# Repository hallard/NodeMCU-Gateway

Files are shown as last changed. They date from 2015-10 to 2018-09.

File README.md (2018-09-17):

NodeMCU ESP8266 Gateway Goes to WeMos ESP8266
=============================================

This gateway has been updated by a new version for the following reasons:

- Now I'm using [WeMos D1 Mini][9] board instead of NodeMCU's one because they're just smaller and cheaper (you can find them for less than $3). 
- Features remains the same, they got lot of available shields
- USB Serial onboard is CH340 instead of CP210x, and I can upload up to 900Kbps without any issue on windows 10
- I suspect WeMos regulator far better quality than the one used on NodeMCU that are just fake of original AMS117 3V3.
- Just one size version, no error on order are possible!
- Only one drawback, Voltage input on WeMos is limited to 6V and NodeMCU says up to 20V but trust me, I burnt some at only 14V so If I need to power boards with more than 6V I'm using cheap and small DC/DC converters like this [one][20]one. Plenty on ebay. If you need a more serious and robust one, take this amazing [OKI-78SR-5][21] from Murata (up to 36V).

So for all these reasons I switched to WeMos and created same shields than the ones described here, but, due to size constraint I removed some features, you need to be aware that the following ones has been removed on WeMos shields:

- SPI 2.2" or 1.8" TFT LCD connector
- SPI 128x64 OLED connector (I2C one still present)
- Grove I2C connector (but I2C is exposed via OLED connector)
- Lipo Battery connector
- Data connection for any cheap ebay ASK RX receiver
- **New, a push button** has been added to do some UI/Action if needed.

WeMos Gateway shields are located here: 
- Shield for [RFM69W, RFM69HW, RFM12B or RFM69CW][10] with Atmel ATSHA204 for crypto
- Shield for Lora/LoraWan [RFM92, RFM95, RFM96 or RFM98][11] with footprint for Microchip 24AA02E64 64 bits serial number
- **New Shield** for Lora/LoraWAN [Microchip RN2483][12] with footprint for excellent Microchip RN2483 Lora/Lorawan Module

Sorry there is no shield designed for NRF24L01.

If you need NRF24L01 version or if you just want to continue with the NodeMCU gateway you can, this repo is still alive and boards are working fine.

NodeMCU ESP8266 Gateway
=======================

The gateway can host several funny things like

- Socket to plug a NodeMCU V1.0 (take care 2 version with different width)
- Pins to connect I2C or SPI OLED 128x64
- Pins to connect 2.2" or 1.8" TFT LCD
- RFM69 or RFM12B on board module
- RFM69, RFM12B or NRF24L01 on board module (on NRF version)
- RFM92, RFM95, RFM96, RFM98, RFMH69, RFMHW69 or RFMHCW69 on board module (on LORA version)
- Lipo Battery connector for testing and move the Gateway (no charger on board)
- 3V3 On board regulator is provided by NodeMCU Board
- Data connection for any cheap ebay ASK RX receiver
- One Grove I2C connector to connect other I2C devices
- 2 onboard nice WS2812 RGB LED
- Footprint for Atmel ATSHA204 (I2C version due to lack of I/O)
- Footprint for Microchip 64 bits Unique ID 24AA02E64  (on LORA version)
- Created a version with NRF24L01 connector instead of a grove I2C (end of this page)
- SMA or UFL Antenna connector 

This page has been updated to reflect the GPIO changes and the PCB also, it's now V1.3.

NRF24L01 version are now tested thanks to [mannkind][6]. As suggested NRF version 1.2 has how been corrected to have NRF24L01 wiring same has mysensors configuration and added place for capacitor near NRF24L01.

LORA version have been tested by [lafleur][7] thanks to him.

Take care that on the market you can find lot of NODEMCU boards with different version, and they do not all fit on this. Just because sometime the width of the board if too high. Take care when you order a NodeMCU, see this [post][8]for explanations

New Version 1.3 boards
======================
New boards version V1.3 these boards have some improvments depending on version
- SMA/UFL Antenna connector has been size reduced
- Antenna trace and RF Module surrounded with via for better RF isolation
- Increased "Isolate" ground planes to avoid shorts between connectors and ground (may happen sometimes after soldering)
- I2C OLED connector is now "lock" version, you can just plug to test it will fit without connector
- No more LED solder pad to choose VIN/3V3, added 1N4148 diode from 5V for the 1st LED to decrease VCC to 4.4V, always works
- LORA version, added Microchip 64 bits Unique ID footprint 24AA02E64 
- LORA version, done a diode logic OR for DIO0/DIO1/DIO2 for current LIMC implementation

Version 1.2 boards
==================
New boards version V1.2 these boards add a MOSFET transistor to protect againns reversed power supply. Trust me this will avoid you to burn some nodeMCU board (but nobody plug reversed powed, never ?)

New board, supporing LORA modules

Version 1.1 boards
==================
Boards V1.1 are tested ok (RFM69), no problem at all, just SILK error on TFT connector, TFT pin 4 is RST or VIN (depending on solder pad) not GPIO0, also R3 10K is not needed since GPIO2 is already pulled up by 12K on nodeMCU boards.

SILK problem solved in V1.1a+, I also put VIN/RST solder pad bigger for easier soldering.

This is a bunch of V1.1 white PCB boards, nice ?

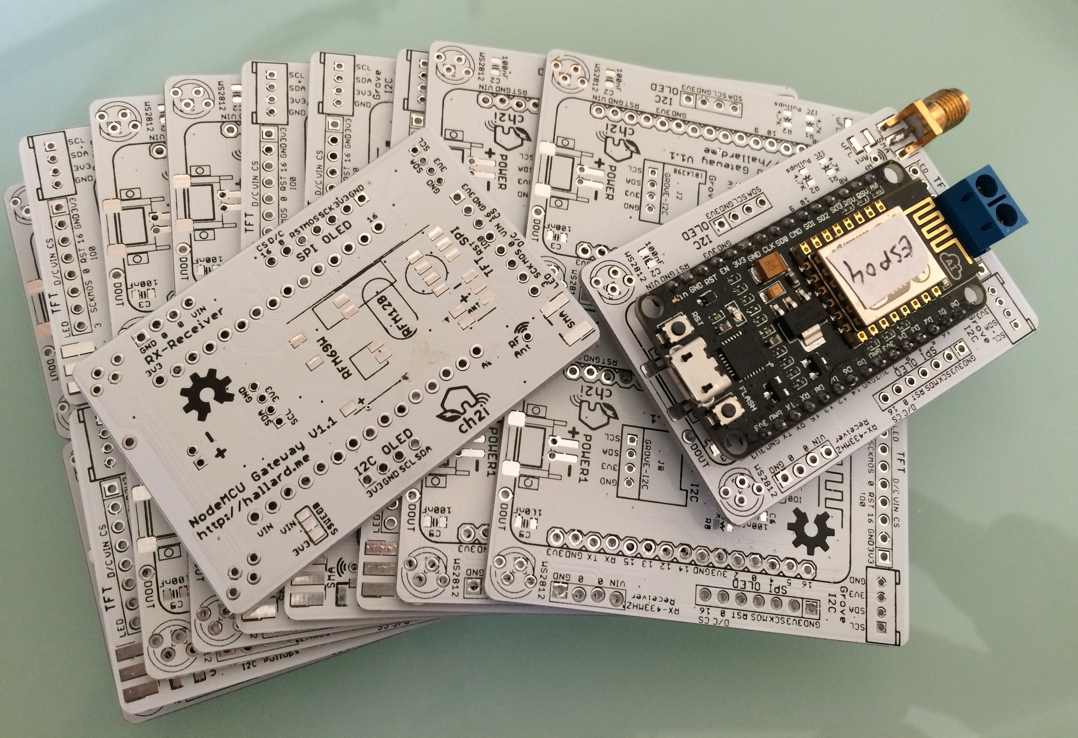
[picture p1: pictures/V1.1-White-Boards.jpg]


Version 1.1 boards
==================
Boards V1.0 worked but I needed a fix for RMF69 pin connection to ESP826 GPIO, let me explain :    
ESP8266 to boot correctly needs some pins at defined level, GPIO15 must be LOW and GPIO2 must be HIGH. Unfortunatlly with RFM69 connected as IRQ to GPIO2 and SS to GPIO15 it does not boot because RF69 pull it DIO IRQ to LOW, making GPIO2 LOW and ESP8266 not booting. The fix is to reverse the wiring, connect IRQ to GPIO15 and SS to GPIO2 (and do according changes in the code).

Detailed Description
====================

No specific documentation for now, but very close in term of feature to Particle Gateway I created and blogged on this dedicated [post][1]

### Schematic (Classic version)
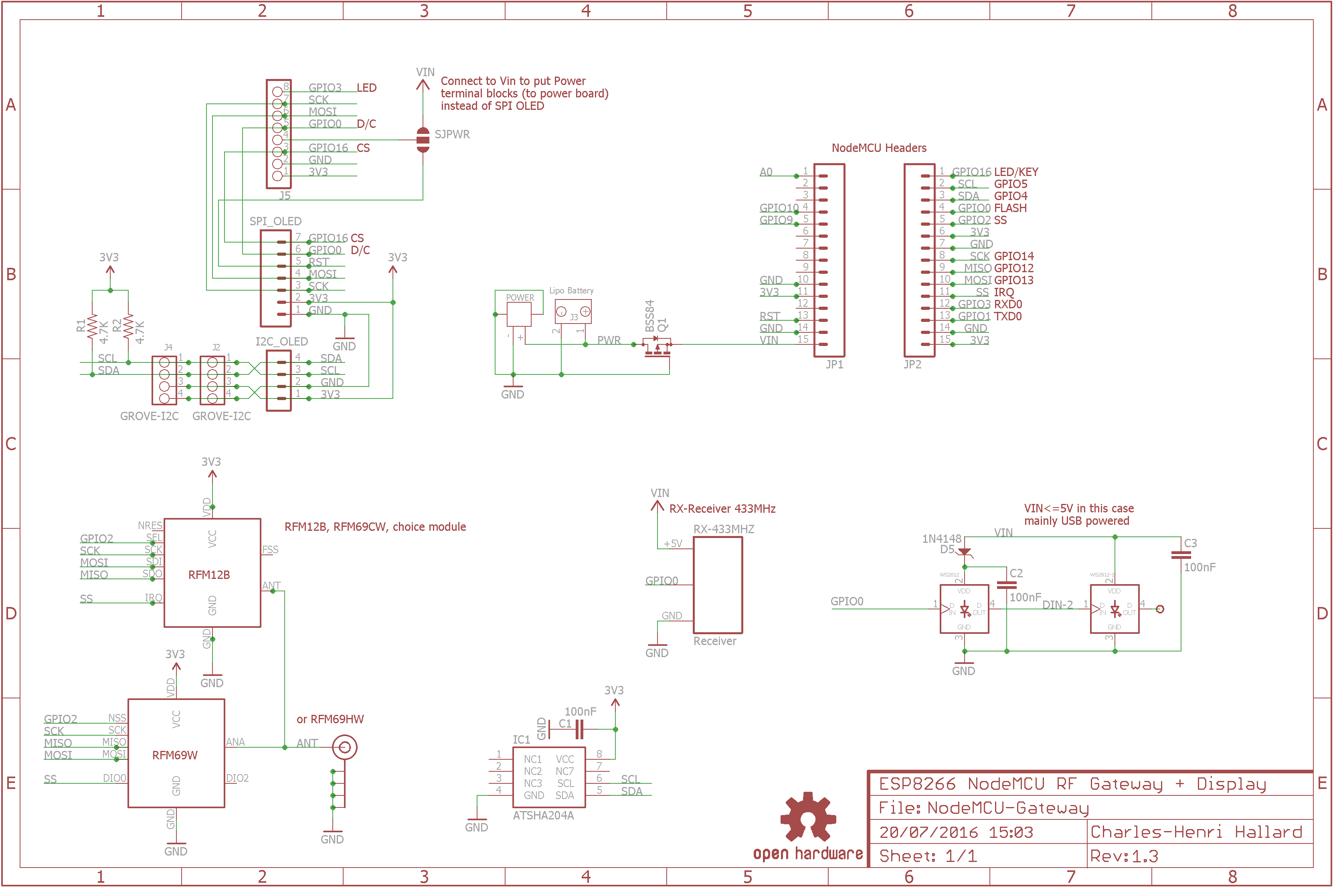
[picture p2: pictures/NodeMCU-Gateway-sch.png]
  

### Boards (Classic version)
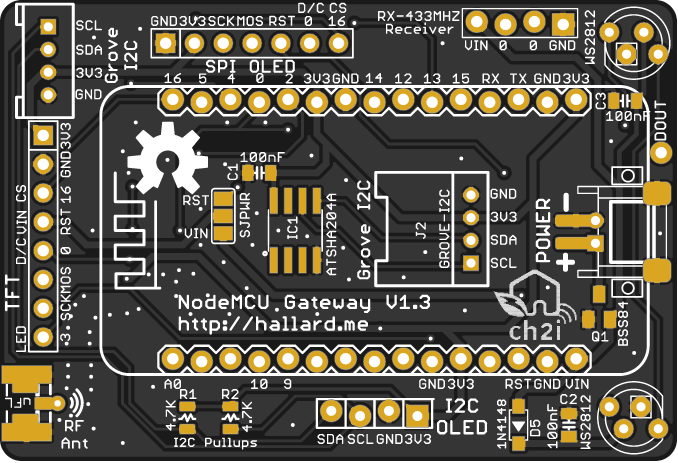
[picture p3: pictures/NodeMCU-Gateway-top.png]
    

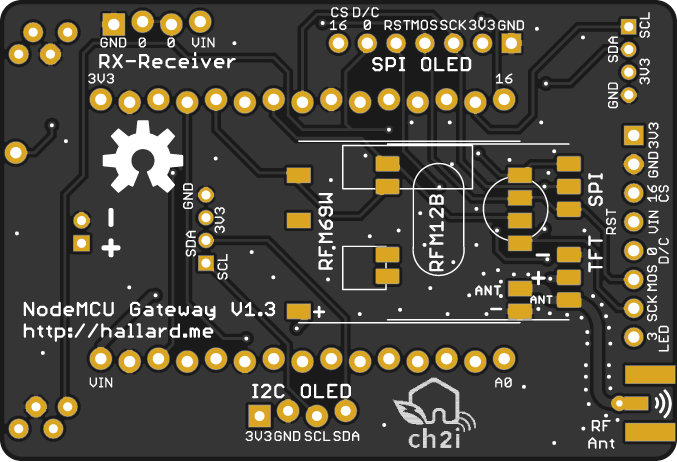
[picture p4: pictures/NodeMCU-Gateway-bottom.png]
Bottom
     

You can order the PCB of this board at [OSHPARK][3] (V1.2) or the new V1.3 version at [PCBs.io][13].
PCBs.io give me some reward when you order my designed boards from their site. This is pretty good, because I can use these rewards to create and design new boards and order boards for a discounted price, so if you don't care about PCB manufacturer please use PCBs.io.

### Assembled boards

*V1.0 tested and assembled boards*    

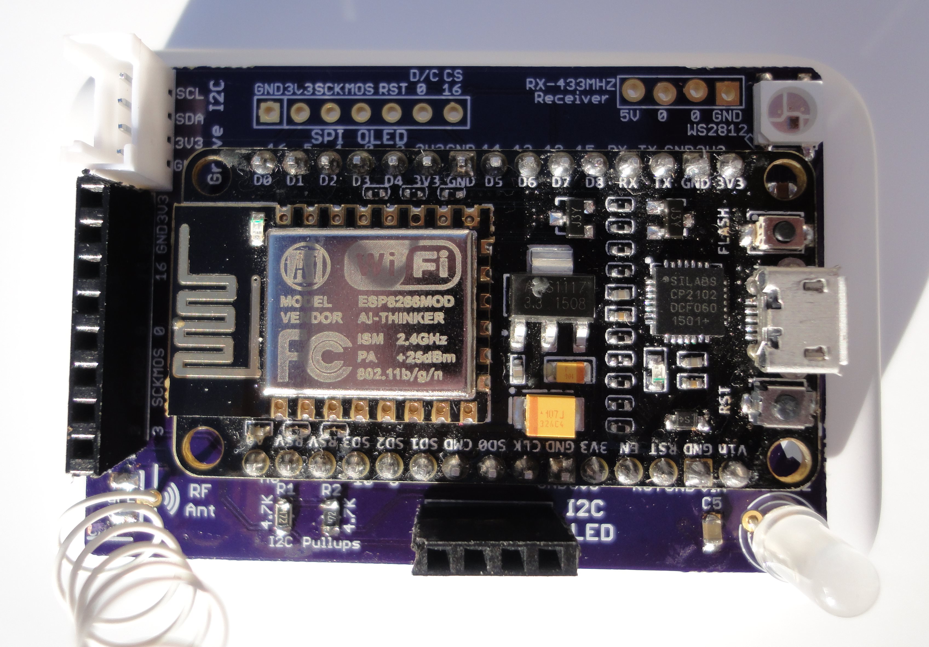
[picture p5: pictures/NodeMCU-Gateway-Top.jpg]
    

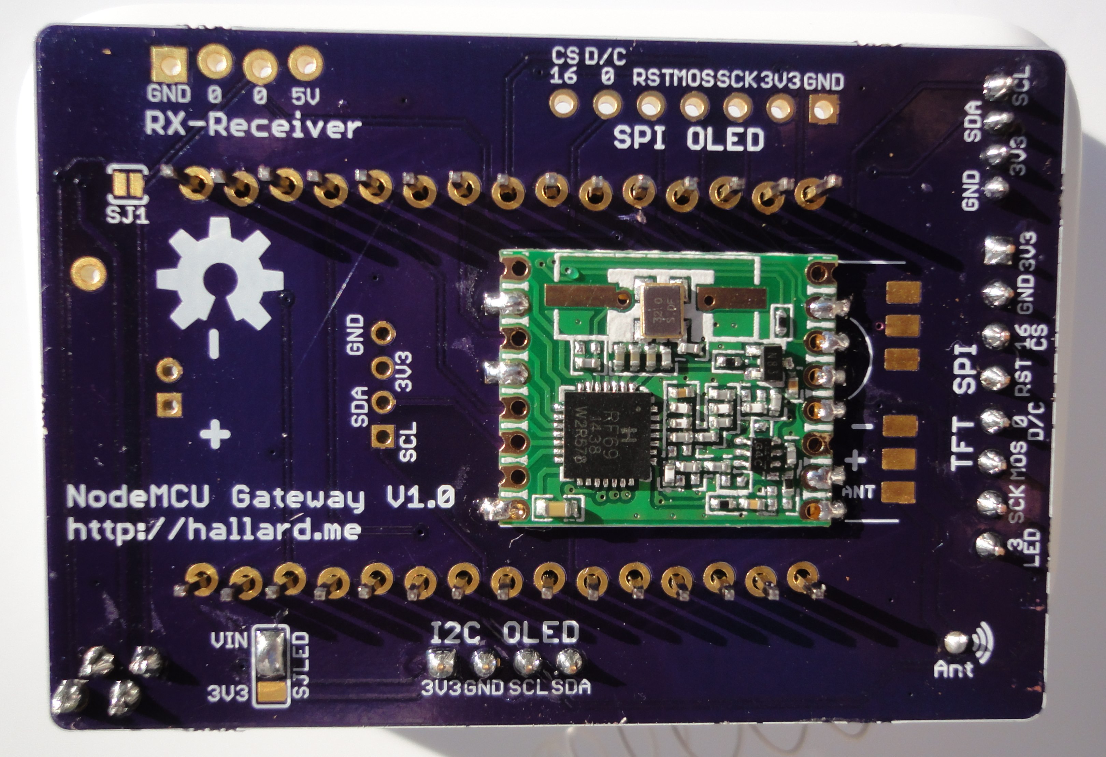
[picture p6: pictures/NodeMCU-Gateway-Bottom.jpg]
Bottom
     

With a nice 1.3" Oled display    
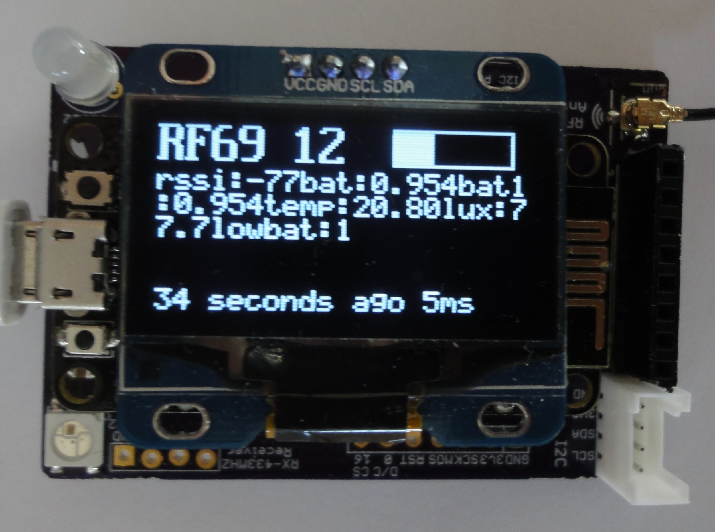
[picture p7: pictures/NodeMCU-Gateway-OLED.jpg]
OLED
    

### Schematic (NRF24L01 version)
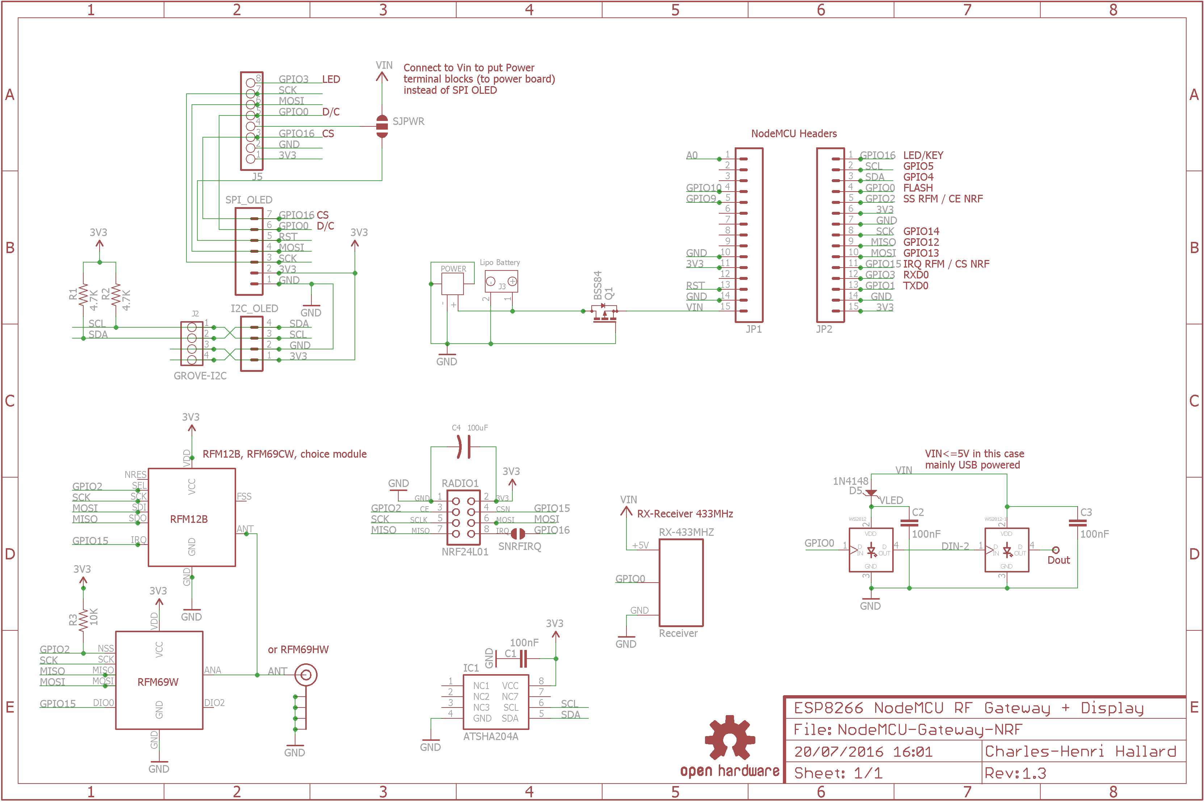
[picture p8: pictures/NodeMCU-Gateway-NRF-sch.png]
  

### Boards (NRF24L01 version)
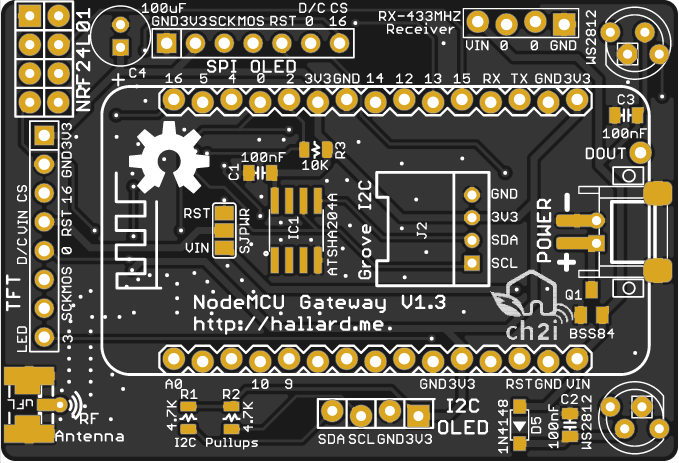
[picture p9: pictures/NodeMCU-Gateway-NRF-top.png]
    

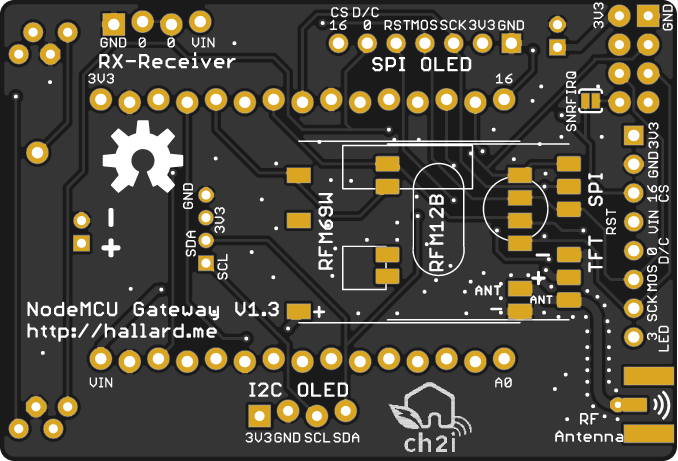
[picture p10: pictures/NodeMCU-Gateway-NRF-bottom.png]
Bottom
     

You can order the PCB of this board at [OSHPARK][4] (V1.2) or the new V1.3 version at [PCBs.io][14].
PCBs.io give me some reward when you order my designed boards from their site. This is pretty good, because I can use these rewards to create and design new boards and order boards for a discounted price, so if you don't care about PCB manufacturer please use PCBs.io.

### Schematic (LORA version)
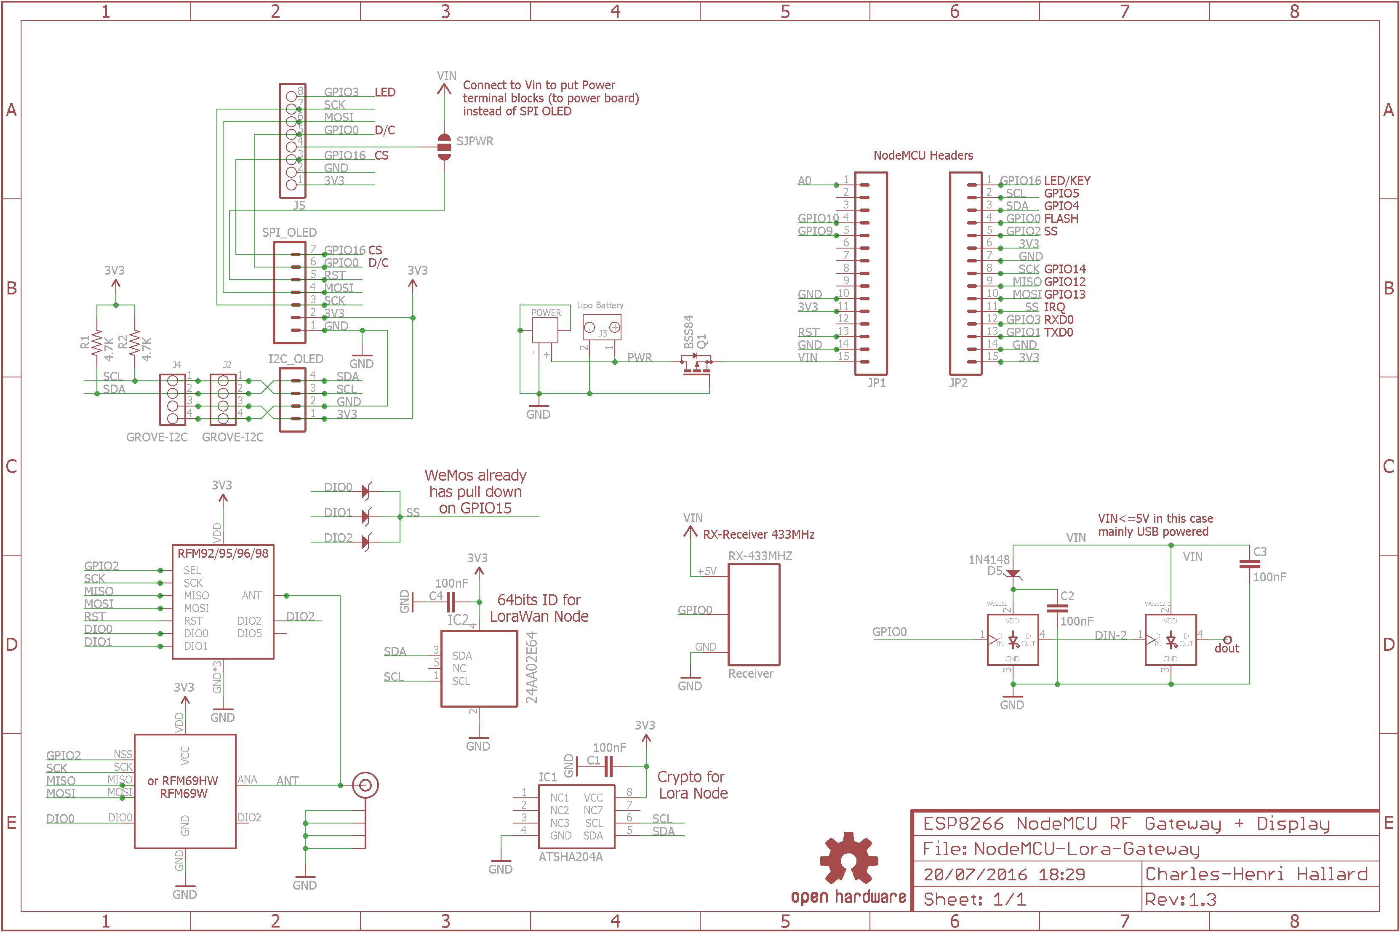
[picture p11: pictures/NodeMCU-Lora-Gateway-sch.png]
  

### Boards (LORA version)
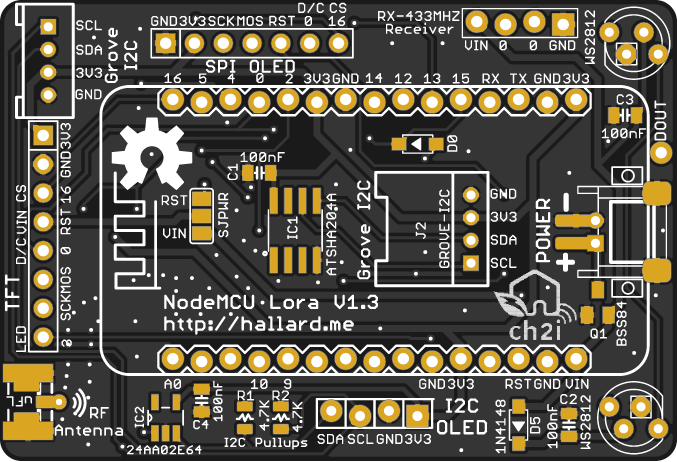
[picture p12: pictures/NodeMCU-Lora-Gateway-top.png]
    

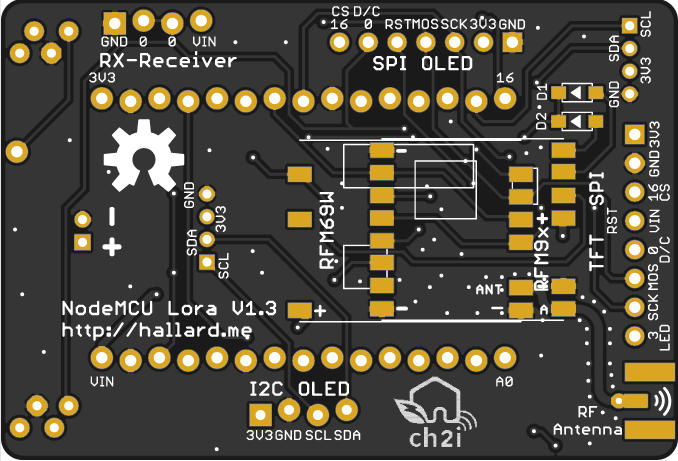
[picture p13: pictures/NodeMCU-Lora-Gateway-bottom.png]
Bottom
     

You can order the PCB of this board at [OSHPARK][5] (V1.2) or the new V1.3 version at [PCBs.io][15].
PCBs.io give me some reward when you order my designed boards from their site. This is pretty good, because I can use these rewards to create and design new boards and order boards for a discounted price, so if you don't care about PCB manufacturer please use PCBs.io.

## Bill Of Material

Nothing fancy, all components are 0805 and can be ordered almost anywhere (digikey, mouser, radiospare, ...) 

The tricky one is the RGB LED called "PL9823 F5" can be found on aliexpress or ebay.

## License

You can do whatever you like with this design.

## Misc
See news and other projects on my [blog][2] 
 
[1]: https://hallard.me/particle-gateway/
[2]: https://hallard.me
[3]: https://oshpark.com/shared_projects/vwEm8gUg
[4]: https://oshpark.com/shared_projects/3wE3bYYY
[5]: https://oshpark.com/shared_projects/HIb6K9BL
[6]: https://github.com/hallard/NodeMCU-Gateway/issues/1
[7]: http://forum.thethingsnetwork.org/t/single-channel-gateway/798/147
[8]: http://forum.thethingsnetwork.org/t/single-channel-gateway/798/145
[9]: http://www.wemos.cc/Products/d1_mini.html
[10]: https://github.com/hallard/WeMos-RFM69
[11]: https://github.com/hallard/WeMos-Lora
[12]: https://github.com/hallard/WeMos-RN2483
[13]: https://PCBs.io/share/z7xX4 
[14]: https://PCBs.io/share/z5yGz 
[15]: https://PCBs.io/share/zvJjz 

[20]: http://www.ebay.com/itm/DC-DC-Step-Down-Buck-Power-Supply-5V-28V-to-3-3V-3A-Precise-Fixed-Output-
[21]: http://www.mouser.fr/Search/Refine.aspx?Keyword=OKI-78SR-5

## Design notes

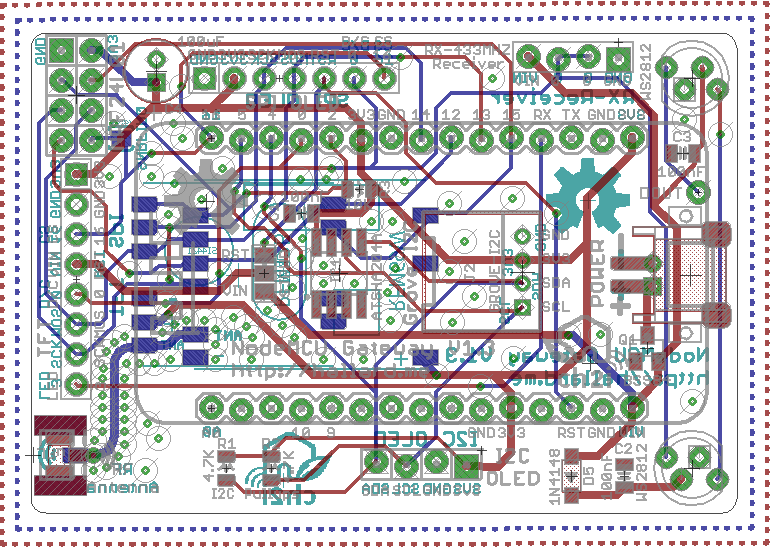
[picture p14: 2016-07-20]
pictures/NodeMCU-Gateway-NRF-brd.png

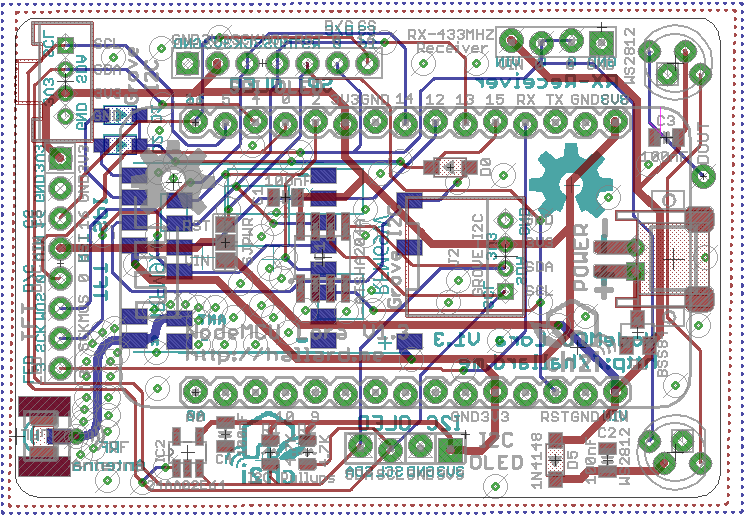
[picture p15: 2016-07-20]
pictures/NodeMCU-Lora-Gateway-brd.png

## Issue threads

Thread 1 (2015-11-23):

Feedback: RF24L01+ Version

mannkind, 2015-11-23:
First, I just wanted to say thanks for creating this PCB! Second, I know that you've documented that you don't use the RF24L01+ radio, but I gave it a try anyway. Indeed, the board does work with a few footnotes:

* NodeMCU Boot Issue: When the RF24L01+ IRQ pin is connected the NodeMCU won't boot
* Board vs MySensors Pinout - Assuming MySensors is part of the reason you created the board, the pinout seems to differ from their [Wifi Gateway Example](http://www.mysensors.org/build/esp8266_gateway)
    * CE - GPIO4
    * CSN/CS - GPIO15
* The RF24L01+ really needs a small 47uF-100uF capacitors; it would be great if there was room on the board (but soldering directly to the radio is an option)

Again, thank you for your work!

hallard, 2015-11-23:
@mannkind
Oh thanks for testing and for your comment. Glad to see it works.
Sorry about the IRQ pin, to be honest 1st proto I made GPIO2 was connected to RFM IRQ and (CS to D15) but as RFM69 was holding the IRQ pin LOW at startup, it prevented ESP to boot, that is why I reversed IRQ and CS lines. It seems on NRF24, IRQ is HIGH at startup (which make more sense than RFM69 setting it LOW)
I should have read about mysensor wiring and do it has they use, in fact I've done it quickly for another project asked on a French  forum. anyway you can cut IRQ line (I think it's what you've done), it's not used by mysensor ;-)

Adding place for capacitor is still doable I think. I will correct this on next revision. Did you tried everything such at the ATSHA204 ? If you need more testing I'll wait before releasing new version.

Thank you for your help

Charles

mannkind, 2015-11-23:
I only have the basics working/tested right now -- the NodeMCU and the RF24L01+.
I have not tried the ATSHA204 yet; according to the [mysensors example sketch](https://github.com/mysensors/Arduino/blob/development/libraries/MySensors/examples/GatewayESP8266MQTTClient/GatewayESP8266MQTTClient.ino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) the ATSHA204 isn't yet supported w/the ESP8266.

hallard, 2015-11-24:
I think they will, if they do a Gateway soft, it should as sensors does ;-)

By the way, I've just released new version V1.2. For NRF Version I made changes according to your suggestions. Hope this help.

Closed 2016-05-04.

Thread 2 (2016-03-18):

Reg LoRa version PCB

asprakash, 2016-03-18:
Hi ,
    I kick started my LoRa module learning phase with HopeRF 92W module. I found this open source project should be very useful for learners. Since I am in India, the final cost  (PCB, Shipping, customs)of the PCB is NOT feasible. I would like to make one at my local facility. May I know can I get the gerber file to fabricate the same PCB at my end?. I also tried some softwares like KiCad & gEDA tools. I am unable to open the schematic file due to some libraries missing. Can you suggest me some tools for how to open the schematic & .brd files on Linux.

Thanks in adv,
Prakash.

hallard, 2016-05-04:
@asprakash
You can open the file and generate gerber with the free version of eagle cad I think
http://www.cadsoftusa.com/download-eagle/

Closed 2016-05-04.

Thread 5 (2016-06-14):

nrf24l01+ and rfm69w

alex1sh, 2016-06-14:
Hi,

Can I mount and use both nrf24l01+ and rfm69w? I have both networks on nrf24 and rfm69w of sensors and having a gateway 3-in-1 is very appealing to me.

Thanks
Alex

hallard, 2016-06-20:
@alex1sh
Well, currently it's not possible since Chip Select pin for both SPI modules (NRF and RFM) are wired to GPIO15. Only way would be

* No IRQ and pool module registers in loop()
* cut one wiring from NSS of one module and link it to another GPIO, not really trivial...

Closed 2018-09-17.

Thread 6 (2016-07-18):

Power issue ?

fab33, 2016-07-18:
It's quite strange I loose a lot of packet with this gateway and USB 2A input on NodeMCU.
Same setup sith another gateway work fine. Did you think NodeMCU can deliver enough power ?

hallard, 2016-07-20:
@fab33
depends on what you power thru the on board NODEMCU 3V3 regulator ?

may be you can try to put big capacitor between 3V3 and GND (470uF or 1000uF)

Closed 2018-09-17.

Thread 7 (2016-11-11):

Gateway v1.3 does not work with RFM95W while v1.2 worked perfectly

dlarue, 2016-11-11:
We ordered a few Gateway 1.3 boards after we were given a V1.2 board and had it working.

I can not find the V1.2 schematic to see what has changed but we've had 2 people assemble the Gateway v1.3 and both cases the NodeMCU would not power up.

dlarue, 2016-11-12:
Digging deeper it appears the NodeMCU Lora V1.2 was marked on the bottom with "NodeMCU Gateway V1.2" and not "NodeMCU Lora Gateway V1.2" as on the top.  Once the NodeMCU is installed only the bottom silkscreen is visible.  So we ordered the wrong boards and V1.3 of the non-Lora will not work.

hallard, 2016-11-15:
@dlarue
the old release could be found on [releases](https://github.com/hallard/NodeMCU-Gateway/releases) section, and you can see difference
Yes there are 3 version each time
 - classic with RFM12B/RFM69
-  same but with NRF24L01 chip
- the lora one for RFM95

But If you want to use the lora one, I strongly recommend the WeMos (same as nodeMCU, but better and smaller) dedicated one
https://github.com/hallard/WeMos-Lora

Closed 2016-11-12.

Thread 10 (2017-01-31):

Role of D0, D1 and D2

drasko, 2017-01-31:
What's the role of these diodes and do I need them if I want simplest GW with NodeMCU board?

drasko, 2017-03-03:
Any updates on this?

drasko, 2017-03-18:
Still no information on this?

hallard, 2018-09-17:
Drasko,
D0, D1 and D2 are used as an OR signal, this permit to couple 3 DIOs outpout of RMF module with only one pin, and yes they are mandatory.

Closed 2018-09-17.

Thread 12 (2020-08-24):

Can't order from pcbs.io?

marcu5au, 2020-08-24:
Hi there,
I love the work you have done and trying to order the NodeMCU-Gateway v1.3 from https://pcbs.io/share/z5yGz but they won't accept any form of payment. Do you know if there are issues with ordering from them or do you have an alternative supplier I can purchase from?
Thanks so much!

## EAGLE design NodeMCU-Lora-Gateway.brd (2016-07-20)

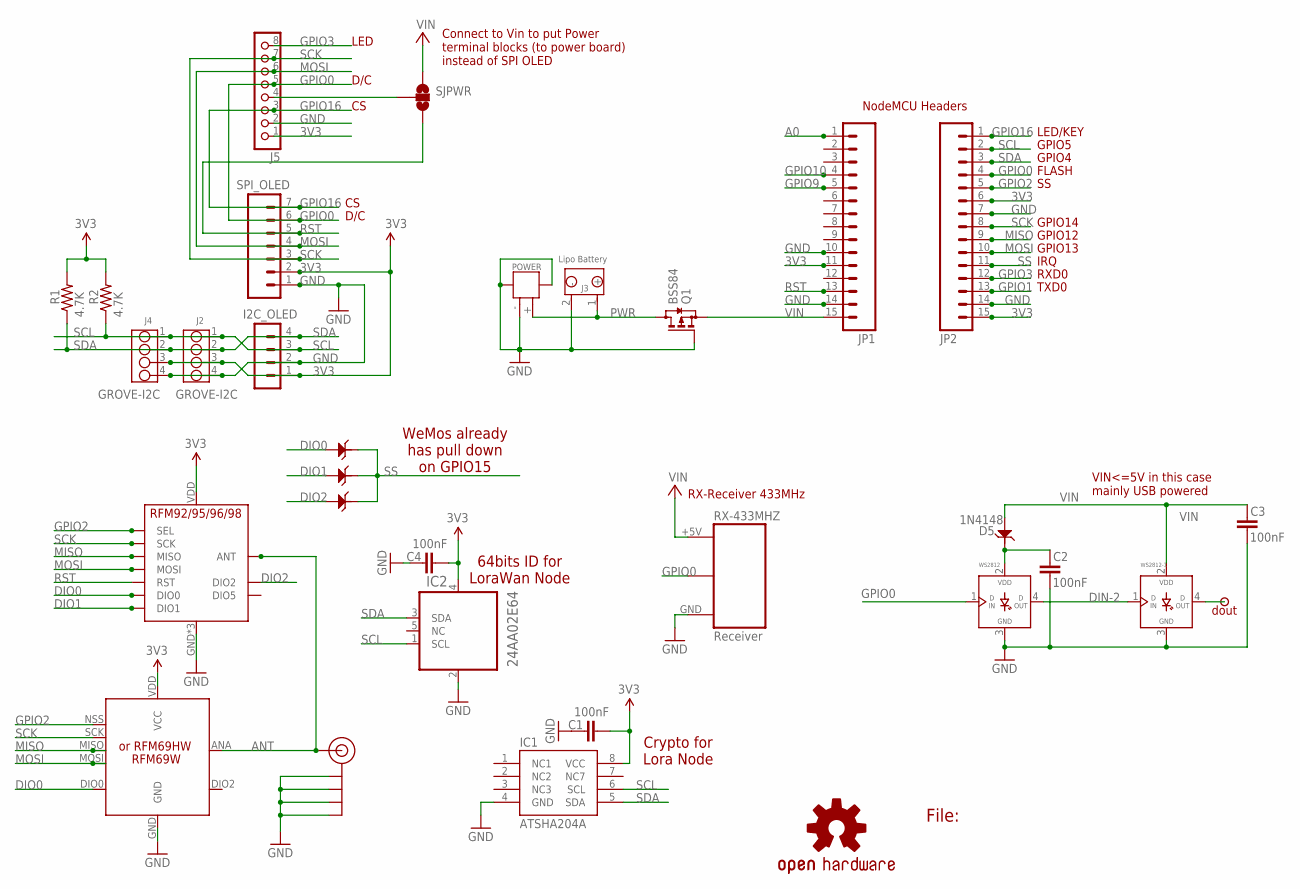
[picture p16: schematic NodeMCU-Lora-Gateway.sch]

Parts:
C1, C2, C3, C4: 100nF; 0805-CAP
D0, D1, D2, D5: 1N4148; SOD123-2.7X1.6
I2C_OLED: CON_HEADER_1X04'LOCK'; 1X04_LOCK
IC1: ATSHA204A; SOIC8
IC2: 24AA02E64; SOT95P270X145-5N
J2: GROVE-I2C; 4P-2.0-90D
J3: Lipo Battery; 2P-2.0-90D
J4: GROVE-I2C; 4P-2.0
J5: CON_HEADER_1X08-PTH; M1X8
J$1: ANTENNATINY; SMA_UFL_PAD_TINY
JP1, JP2: M15LOCK; 1X15_LOCK
LOGO2: OSHW-LOGOL; OSHW-LOGO-L
P2: PADNORMAL; PAD
POWER: JST-2P-SMD'2.0'; 2P-SMD-2.0-90D
Q1: BSS84; SOT23
R1, R2: 4.7K; 0805-RES
RX-433MHZ: Receiver; RF-LINK_RX_NO_SILK
SJPWR: JUMPER-PAD-3-2OF3_NC_BY_TRACE_LARGE; PAD-JUMPER-3-2OF3_NC_BY_TRACE_YES_SILK_LARGE
SPI_OLED: CON_HEADER_1X07'SMALL'; M1X7
U1: RFM9x; RFM95
U$3: RFM69W; RFM69W-MINPADS
WS2812, WS2812-1: WS2812B; WS2812-PTH

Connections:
3V3: C1.2, C4.2, I2C_OLED.1, IC1.8 (VCC), IC2.4 (VCC), J2.3, J4.3, J5.1, JP1.11, JP2.6, JP2.15, R1.2, R2.2, SPI_OLED.2, U1.VDD (VCC), U$3.VDD (VCC)
A0: JP1.1
ANT: J$1.ANT1 (SIGNAL), J$1.ANT2 (SIGNAL), J$1.ANT3 (SIGNAL), U1.ANT, U$3.ANA (ANT)
DIN-2: WS2812.4 (DOUT), WS2812-1.1 (DIN)
DIO0: D0.1, U1.DIO0, U$3.DIO0
DIO1: D1.1, U1.DIO1
DIO2: D2.1, U1.DIO2
GND: C1.1, C2.1, C3.1, C4.1, I2C_OLED.2, IC1.4 (GND), IC2.2 (VSS), J2.4, J3.2 (-), J4.4, J5.2, J$1.GND1 (GND), J$1.GND2 (GND), J$1.GND3 (GND), J$1.GND4 (GND), JP1.10, JP1.14, JP2.7, JP2.14, POWER.3, POWER.4, POWER.- (2), Q1.1 (G), RX-433MHZ.GND, SPI_OLED.1, U1.GND, U1.GND1 (GND), U1.GND2 (GND), U$3.GND, WS2812.3 (GND), WS2812-1.3 (GND)
GPIO0: J5.5, JP2.4, RX-433MHZ.DATA@1 (DATA), RX-433MHZ.DATA@2 (DATA), SPI_OLED.6, WS2812.1 (DIN)
GPIO1: JP2.13
GPIO2: JP2.5, U1.NSS (SEL), U$3.NSS (SEL)
GPIO3: J5.8, JP2.12
GPIO9: JP1.5
GPIO10: JP1.4
GPIO16: J5.3, JP2.1, SPI_OLED.7
MISO: JP2.9, U1.MISO, U$3.MISO
MOSI: J5.6, JP2.10, SPI_OLED.4, U1.MOSI, U$3.MOSI
unnamed: P2.1, WS2812-1.4 (DOUT)
unnamed: J5.4, SJPWR.2
PWR: J3.1 (+), POWER.+ (1), Q1.3 (D)
RST: JP1.13, SJPWR.3, SPI_OLED.5, U1.RST
SCK: J5.7, JP2.8, SPI_OLED.3, U1.SCK, U$3.SCK
SCL: I2C_OLED.3, IC1.6 (SCL), IC2.1 (SCL), J2.1, J4.1, JP2.2, R2.1
SDA: I2C_OLED.4, IC1.5 (SDA), IC2.3 (SDA), J2.2, J4.2, JP2.3, R1.1
SS: D0.2, D1.2, D2.2, JP2.11
VIN: C3.2, D5.1, JP1.15, Q1.2 (S), RX-433MHZ.+5V, SJPWR.1, WS2812-1.2 (VDD)
VLED: C2.2, D5.2, WS2812.2 (VDD)

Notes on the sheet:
or RFM69HW
RX-Receiver 433MHz
D/C
LED
File:
FLASH
GPIO12
GPIO4
GPIO5
RXD0
TXD0
GPIO13
GPIO14
IRQ
LED/KEY
NodeMCU Headers
Connect to Vin to put Power terminal blocks (to power board) instead of SPI OLED
VIN<=5V in this case mainly USB powered
dout
64bits ID for LoraWan Node
Crypto for Lora Node
WeMos already has pull down on GPIO15

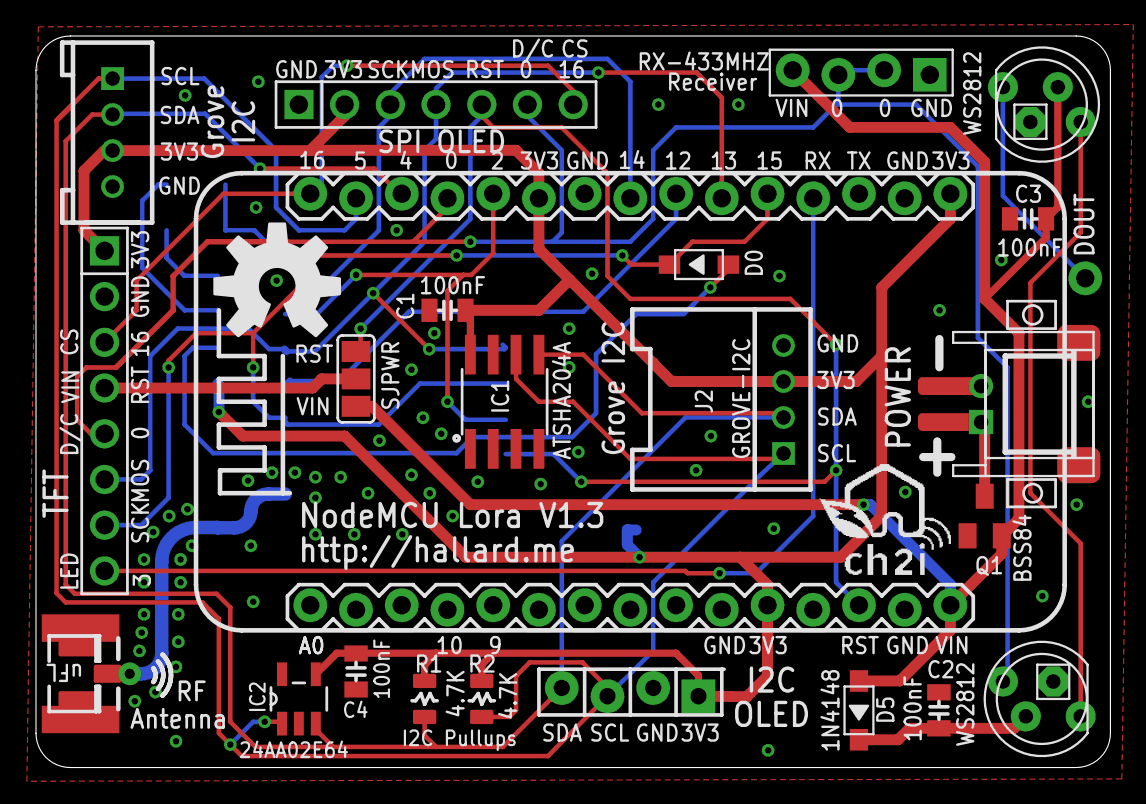
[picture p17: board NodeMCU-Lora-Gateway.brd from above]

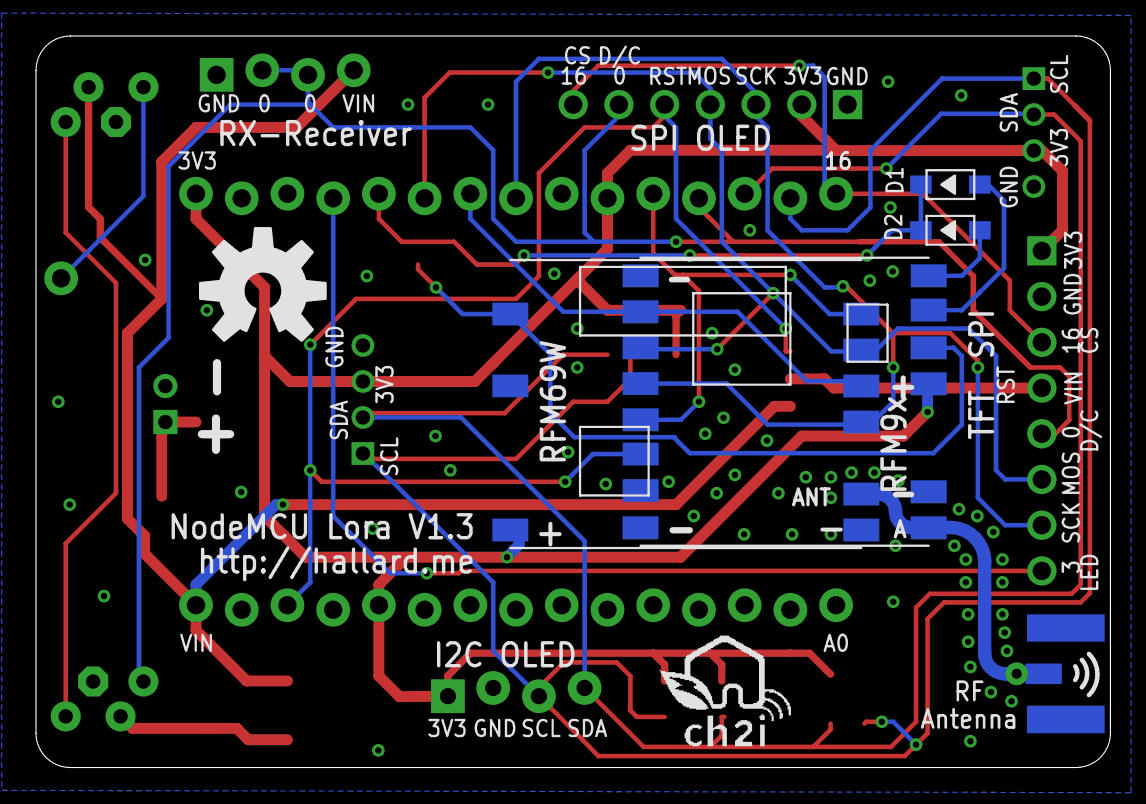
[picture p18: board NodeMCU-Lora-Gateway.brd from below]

Board: 2 copper layers, 59.7 x 40.6 mm, 34 parts (6 on the bottom side), 23 nets.

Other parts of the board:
LOGO1: OSHW-LOGOL; OSHW-LOGO-L
U$1, U$4: LOGO_CH2I_75MM

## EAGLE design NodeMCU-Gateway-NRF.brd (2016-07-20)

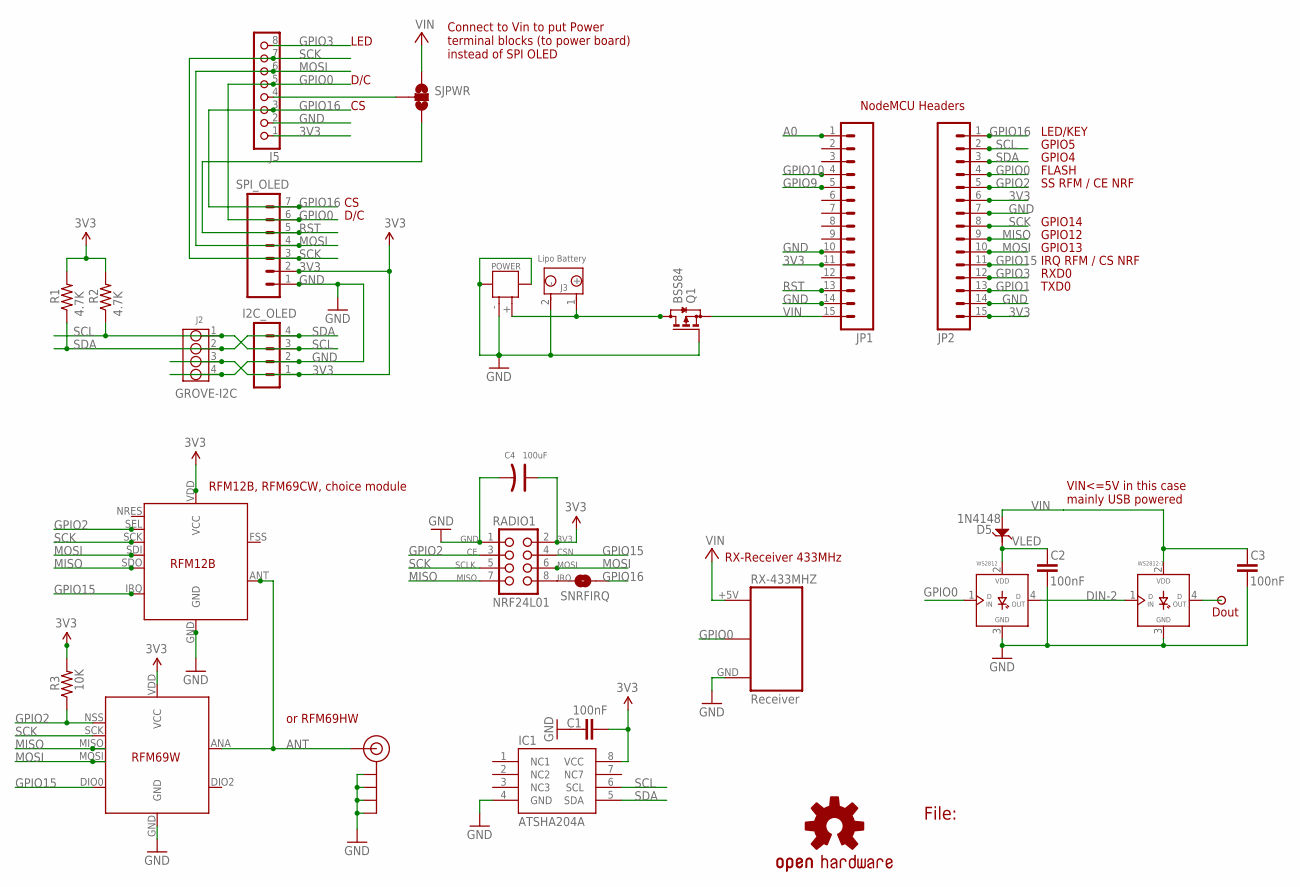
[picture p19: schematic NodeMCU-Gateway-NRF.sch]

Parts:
C1, C2, C3: 100nF; 0805-CAP
C4: 100uF; RADIAL-2.0-D5.0*H7MM
D5: 1N4148; SOD123-2.7X1.6
I2C_OLED: CON_HEADER_1X04'LOCK'; 1X04_LOCK
IC1: ATSHA204A; SOIC8
J2: GROVE-I2C; 4P-2.0-90D
J3: Lipo Battery; 2P-2.0-90D
J5: CON_HEADER_1X08-PTH; M1X8
J$2: ANTENNATINY; SMA_UFL_PAD_TINY
JP1, JP2: M15LOCK; 1X15_LOCK
LOGO2: OSHW-LOGOL; OSHW-LOGO-L
P2: PADNORMAL; PAD
POWER: JST-2P-SMD'2.0'; 2P-SMD-2.0-90D
Q1: BSS84; SOT23
R1, R2: 4.7K; 0805-RES
R3: 10K; 0805-RES
RADIO1: NRF24L01; 2X04_NO_LOCK
RX-433MHZ: Receiver; RF-LINK_RX_NO_SILK
SJPWR: JUMPER-PAD-3-2OF3_NC_BY_TRACE_LARGE; PAD-JUMPER-3-2OF3_NC_BY_TRACE_YES_SILK_LARGE
SNRFIRQ: NRFIRQ; PAD-JUMPER-2-NO_YES_SILK
SPI_OLED: CON_HEADER_1X07'SMALL'; M1X7
U$2: RFM12B; RFM12B-MINPADS
U$3: RFM69W; RFM69W-MINPADS
WS2812, WS2812-1: WS2812B; WS2812-PTH

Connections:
3V3: C1.2, C4.+, I2C_OLED.1, IC1.8 (VCC), J2.3, J5.1, JP1.11, JP2.6, JP2.15, R1.2, R2.2, R3.2, RADIO1.2 (3V3), SPI_OLED.2, U$2.VDD (VCC), U$3.VDD (VCC)
A0: JP1.1
ANT: J$2.ANT1 (SIGNAL), J$2.ANT2 (SIGNAL), J$2.ANT3 (SIGNAL), U$2.ANT, U$3.ANA (ANT)
DIN-2: WS2812.4 (DOUT), WS2812-1.1 (DIN)
GND: C1.1, C2.1, C3.1, C4.-, I2C_OLED.2, IC1.4 (GND), J2.4, J3.2 (-), J5.2, J$2.GND1 (GND), J$2.GND2 (GND), J$2.GND3 (GND), J$2.GND4 (GND), JP1.10, JP1.14, JP2.7, JP2.14, POWER.3, POWER.4, POWER.- (2), Q1.1 (G), RADIO1.1 (GND), RX-433MHZ.GND, SPI_OLED.1, U$2.GND, U$3.GND, WS2812.3 (GND), WS2812-1.3 (GND)
GPIO0: J5.5, JP2.4, RX-433MHZ.DATA@1 (DATA), RX-433MHZ.DATA@2 (DATA), SPI_OLED.6, WS2812.1 (DIN)
GPIO1: JP2.13
GPIO2: JP2.5, R3.1, RADIO1.3 (CE), U$2.SEL, U$3.NSS (SEL)
GPIO3: J5.8, JP2.12
GPIO9: JP1.5
GPIO10: JP1.4
GPIO15: JP2.11, RADIO1.4 (CSN), U$2.IRQ, U$3.DIO0
GPIO16: J5.3, JP2.1, SNRFIRQ.2, SPI_OLED.7
MISO: JP2.9, RADIO1.7 (MISO), U$2.SDO, U$3.MISO
MOSI: J5.6, JP2.10, RADIO1.6 (MOSI), SPI_OLED.4, U$2.SDI, U$3.MOSI
unnamed: P2.1, WS2812-1.4 (DOUT)
unnamed: J5.4, SJPWR.2
unnamed: RADIO1.8 (IRQ), SNRFIRQ.1
PWR: J3.1 (+), POWER.+ (1), Q1.3 (D)
RST: JP1.13, SJPWR.3, SPI_OLED.5
SCK: J5.7, JP2.8, RADIO1.5 (CLK), SPI_OLED.3, U$2.SCK, U$3.SCK
SCL: I2C_OLED.3, IC1.6 (SCL), J2.1, JP2.2, R2.1
SDA: I2C_OLED.4, IC1.5 (SDA), J2.2, JP2.3, R1.1
VIN: C3.2, D5.1, JP1.15, Q1.2 (S), RX-433MHZ.+5V, SJPWR.1, WS2812-1.2 (VDD)
VLED: C2.2, D5.2, WS2812.2 (VDD)

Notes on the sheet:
RFM12B, RFM69CW, choice module
or RFM69HW
RX-Receiver 433MHz
D/C
LED
File:
SS RFM / CE NRF
FLASH
GPIO12
GPIO4
GPIO5
RXD0
TXD0
GPIO13
GPIO14
IRQ RFM / CS NRF
LED/KEY
NodeMCU Headers
Connect to Vin to put Power terminal blocks (to power board) instead of SPI OLED
VIN<=5V in this case mainly USB powered
Dout

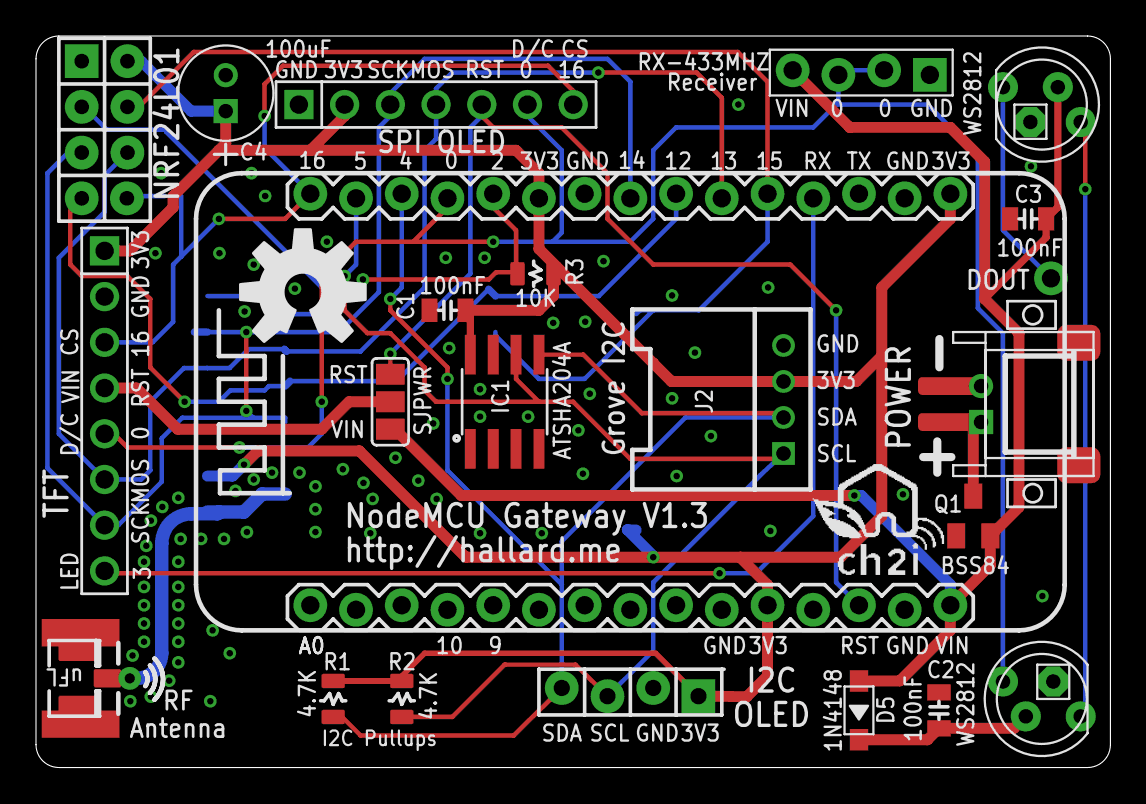
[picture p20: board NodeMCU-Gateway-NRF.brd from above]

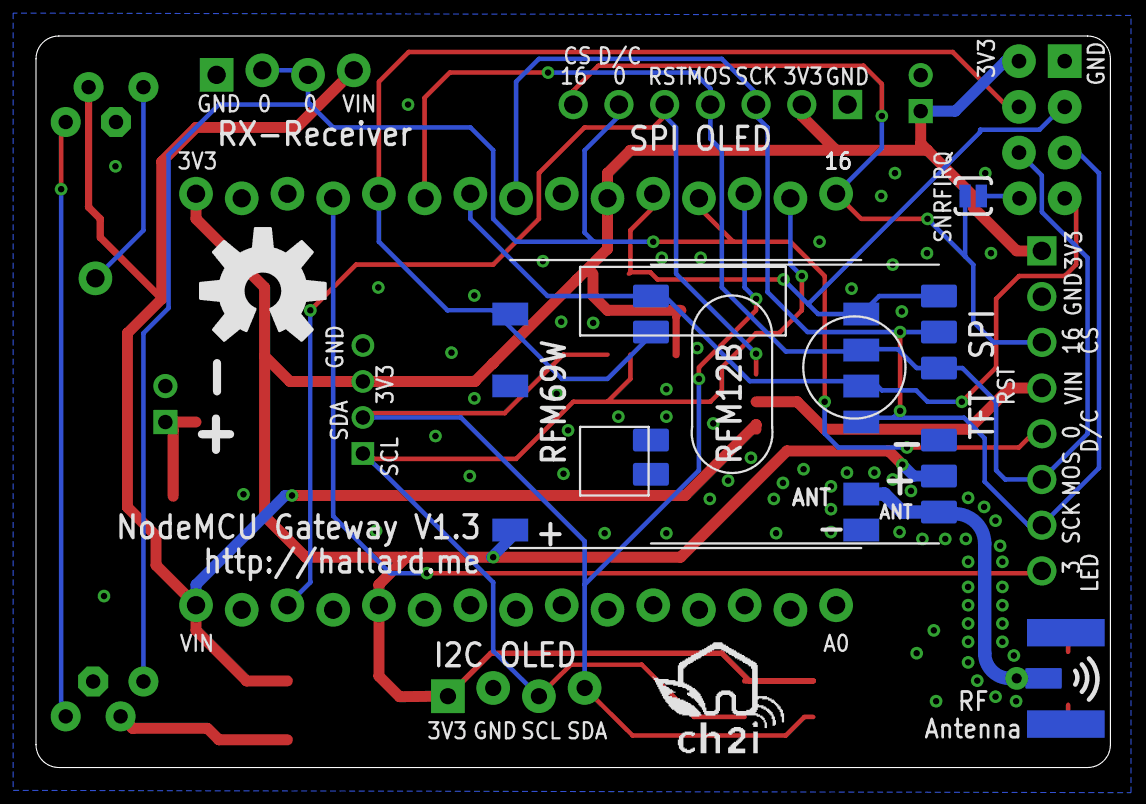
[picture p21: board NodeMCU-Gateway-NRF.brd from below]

Board: 2 copper layers, 59.7 x 40.6 mm, 32 parts (5 on the bottom side), 21 nets.

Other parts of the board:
LOGO1: OSHW-LOGOL; OSHW-LOGO-L
U$6, U$7: LOGO_CH2I_75MM

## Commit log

2015-08-28 Increased boards image size
2015-10-03 Version 1.1
    [NodeMCU-Gateway.brd, NodeMCU-Gateway.sch]
2015-10-03 Added RGB LED
2015-10-03 Added description on assembled boards
2015-10-04 Added Footprint for ATSHA204
    [NodeMCU-Gateway.brd, NodeMCU-Gateway.sch]
2015-10-06 Création version NRF24L01
    [NodeMCU-Gateway-NRF.brd, NodeMCU-Gateway-NRF.sch]
2015-10-06 Added NRF24 schematic version
2015-10-14 Adjust SMA and UFL connectors
    [NodeMCU-Gateway.brd, NodeMCU-Gateway.sch]
2015-10-31 Silk error
    Silk SJPWR is not tied to GPIO0 but RST/VIN
    Increased SJPWR size for easy soldering
    [NodeMCU-Gateway-NRF.brd, NodeMCU-Gateway-NRF.sch]
2015-10-31 Minor Silk Error
    Silk SJPWR not tied to GPIO0 but RST/VIN
    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
    [NodeMCU-Gateway.brd, NodeMCU-Gateway.sch]
2015-10-31 Added White PCB picture
2015-11-23 Version 1.1b
    NRF24L01 wiring same as mysensor gateway
    Added place to add cap near NRF24L01
    [NodeMCU-Gateway-NRF.brd, NodeMCU-Gateway-NRF.sch]
2015-11-23 Version 1.2
    Added FET to protect in case of power reverse, this avoid burning
    NodeMCU board
    [NodeMCU-Gateway-NRF.brd, NodeMCU-Gateway-NRF.sch, NodeMCU-Gateway.brd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]
2015-11-23 Creation
    Direct to V1.2 to conform all other boards and release
    [NodeMCU-Lora-Gateway.brd, NodeMCU-Lora-Gateway.sch]
2016-07-20 Bump to V1.3
    * SMA/UFL Antenna connector has been size reduced
    * Antenna trace and RF Module surrounded with via for better RF
    isolation
    * I2C OLED connector is now "lock" version, you can just plug to test it
    will fit without connector
    * No more LED solder pad to choose VIN/3V3, added 1N4148 diode from 5V
    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
    [NodeMCU-Gateway.brd, NodeMCU-Gateway.sch]
2016-07-20 Bump to V1.3
    * Increased "Isolate" ground planes to avoid shorts between connectors
    and ground (may happen sometimes after soldering)
    for the 1st LED to decrease VCC to 4.4V, always works
    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
    [NodeMCU-Gateway-NRF.brd, NodeMCU-Gateway-NRF.sch]
2016-07-20 Bump to V1.3 version
    * LORA version, added Microchip 64 bits Unique ID footprint 24AA02E64
    * LORA version, done a diode logic OR for DIO0/DIO1/DIO2 for current
    LIMC implementation
    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
    [NodeMCU-Lora-Gateway.brd, NodeMCU-Lora-Gateway.sch]
2016-08-03 Added links to WeMos boards

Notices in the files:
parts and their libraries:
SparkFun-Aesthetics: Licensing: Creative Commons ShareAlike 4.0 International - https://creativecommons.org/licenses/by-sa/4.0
